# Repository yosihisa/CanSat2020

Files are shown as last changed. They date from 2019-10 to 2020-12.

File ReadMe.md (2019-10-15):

# CanSat2020 
2020ねん9がつ の あーりす はつさんか はつゆうしょう を めざす リポジトリ だよ 。  

## コンセプト
  - 今までにない軽さ 
  - 高い耐久性
  - 高い信頼性
  - 早い開発サイクル
  - 軽くて最強の大型CanSat

## 開発目標  

期間 | モデル | 目標
--- | --- | ---
～2019年12月 | Prototype | 大型機の技術獲得　新要素の動作試験  
～2020年3月 | TRC16 (EM) | 耐久試験①　種コン2連覇  
～2020年8月 | NSE16 (PFM) | 耐久試験②　長距離通信技術の獲得　航続距離の向上  
～2020年9月 | ARLISS2020 (FM) | 最強CanSat完成  

モデル名とタグ名が対応

## 構成

場所 | 名称 | 役割
--- | --- | ---
(あとでA360のURLを貼る) | 構造 | 構造系全般
/PCB | 基板 | 電装系(ハード)
/firmware/main | ソースコード(メイン) | メインMCU
/firmware/sub | ソースコード(サブ) | 画像処理系　画像記録系
/tools | ツール | 運用に便利な道具たち
/doc | Document | 開発メモとか資料とか

## システム図

にゃーん

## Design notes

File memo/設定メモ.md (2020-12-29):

# VScodeでSTM32を開発するためのメモ

## やりたい事
CubeMXでmakefileプロジェクトとして生成→VScodeで編集→VScodeでコンパイル→VScodeで書き込み→VScodeでデバッグ  

## 初回のみ必要な作業(使用するツールのインストール)  
インストールといっても今回は環境変数を変更しないため、適当なディレクトリに展開するだけです。
### ツール
- GNU ARM Embedded Toolchain  
- OpenOCD  
- Make for Windows  
- LibIntl for Windows  
- LibIconv for Windows  
こいつらを`C:\tools`以下に展開  

場所  
- `C:\tools\gcc-arm-none-eabi-9-2019-q4-major-win32\bin`  
- `C:\tools\OpenOCD\0.10.0-12-20190422-2015\bin`  
- `C:\tools\make-3.81-bin\bin`  
- `C:\tools\make-3.81-bin\bin\libintl3.dll`  
- `C:\tools\make-3.81-bin\bin\libiconv2.dll`  

### 拡張機能
- C/C++  
- Cortex-Debug  

## プロジェクトごとに必要な設定  

### .vscode\tasks.json  

```json
{
    "version": "2.0.0",
    "type": "shell",
    "echoCommand": true,
    "tasks": [
        {
            "label": "Build project",
            "command": "make",
            "args": [
                "all",
                "GCC_PATH=C:\\tools\\gcc-arm-none-eabi-9-2019-q4-major-win32\\bin"
            ],
            "options": {
                "env": {
                    "PATH": "C:\\tools\\make-3.81-bin\\bin"
                }
            },
            "problemMatcher": [
                "$gcc"
            ],
            "group": {
                "kind": "build",
                "isDefault": true
            }
        },
        {
            "label": "Clean project",
            "command": "Remove-Item",
            "args": [
                "build",
                "-Recurse"
            ],
            "problemMatcher": [
                "$gcc"
            ],
            "group": {
                "kind": "build",
                "isDefault": true
            }
        }
    ]
}
```

### launch.json

```json
{
    "version": "0.2.0",
    "configurations": [
        {
            "name": "Cortex Debug",
            "cwd": "${workspaceRoot}",
            "executable": "./build/${workspaceFolderBasename}.elf",
            "request": "launch",
            "type": "cortex-debug",
            "servertype": "openocd",
            "configFiles": [
                "board/st_nucleo_f4.cfg"
            ],
            "preLaunchTask": "Build project",
            "armToolchainPath": "C:\\tools\\gcc-arm-none-eabi-9-2019-q4-major-win32\\bin\\",
            "serverpath": "C:\\tools\\OpenOCD\\0.10.0-12-20190422-2015\\bin\\openocd.exe"
        }
    ]
}
```

もしくは

```json

            "configFiles": [
                "interface/stlink-v2-1.cfg",
                "target/stm32f4.cfg"
            ],
```

### makefile  

ソースファイルを追加したら以下の場所にパスを追加する。

```makefile
# C sources
C_SOURCES =  \
Src/main.c \
...
```

RAMやROMの使用率を表示するには以下の設定をしておくと便利。
`,-print-memory-usage`を末尾に追加する。
`printf`で`float`を使う場合も同じように`u _printf_float`を末尾に追加する。

```makefile
# libraries
LIBS = -lc -lm -lnosys 
LIBDIR = 
LDFLAGS = $(MCU) -specs=nano.specs <中略> ,-print-memory-usage
```

### .vscode\c_cpp_properties.json  
必須ではないが設定しておくとintellisenseが機能するようになるので便利。 

```json
{
    "configurations": [
        {
            "name": "STM32",
            "includePath": [
                "${workspaceFolder}/**",
                "C:\\tools\\gcc-arm-none-eabi-9-2019-q4-major-win32\\arm-none-eabi\\include**",
                "C:\\tools\\gcc-arm-none-eabi-9-2019-q4-major-win32\\lib\\gcc\\arm-none-eabi\\9.2.1\\include"
            ],
            "defines": [
                "USE_HAL_DRIVER",
                "STM32F446xx",
                "__weak=__attribute__((weak))"
            ],
            "compilerPath": "C:\\tools\\gcc-arm-none-eabi-9-2019-q4-major-win32\\bin\\arm-none-eabi-gcc",
            "cStandard": "c11",
            "cppStandard": "c++17",
            "intelliSenseMode": "clang-x64"
        }
    ],
    "version": 4
}
```

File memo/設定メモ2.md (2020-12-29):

# ライブラリを共通化するための方法

## やりたい事
CubeMXで生成したファイルと自前のライブラリを共通化しつつ、main.cなどのファイルはプログラムごとに分離したい

## ディレクトリ構成

```
hoge/
　├ .vscode/
　│　├ c_cpp_properties.json
　│　├ launch.json
　│　├ tasks.json
　│　└...
　│
　├ common/      ←自作ライブラリのディレクトリ
　│　├ Inc/
　│　│  └ *.h
　│　└ Src/
　│　   └ *.c
　│
　├ Drivers/     ←CubeMXにより自動生成
　├ Inc/         ←CubeMXにより自動生成
　│
　├ Project1/    ←自分で書くコード1
　│　├ main.c
　│　├ Makefile
　│　├ hogehoge.c
　│　├ hogehoge.h
　│　└...
　│
　├ Project2/    ←自分で書くコード2
　│　├ main.c
　│　├ Makefile
　│　├ hogehoge.c
　│　├ hogehoge.h
　│　└...
　│
　├ Src/        ←CubeMXにより自動生成
　├ .mxproject  ←CubeMXにより自動生成
　├ hoge.ioc    ←CubeMXにより自動生成
　├ Makefile    ←CubeMXにより自動生成
　└ ...
```

## 各種設定  

### CubeMXの設定  
Project Manager -> Code Generator -> Generate peripheral initialaization as a pair of '.c/.h' files per peripheral を有効にする。

### tasks.json  

```json
{
    "version": "2.0.0",
    "type": "shell",
    "echoCommand": true,
    "tasks": [
        {
            "label": "Build project",
            "command": "make",
            "args": [
                "all",
                "GCC_PATH=C:\\tools\\gcc-arm-none-eabi-9-2019-q4-major-win32\\bin",
                "SRC_PATH=${fileDirname}",
                "-j4"
            ],
            "options": {
                "env": {
                    "PATH": "C:\\tools\\make-3.81-bin\\bin"
                }
            },
            "problemMatcher": [
                "$gcc"
            ],
            "group": {
                "kind": "build",
                "isDefault": true
            }
        },
        {
            "label": "Clean project",
            "command": "Remove-Item",
            "args": [
                "${fileDirname}\\build",
                "-Recurse"
            ],
            "problemMatcher": [
                "$gcc"
            ],
            "group": "build"
        }
    ]
}
```

### launch.json

```json
{
    "version": "0.2.0",
    "configurations": [
        {
            "name": "Cortex Debug",
            "cwd": "${workspaceRoot}",
            "executable": "${fileDirname}/build/${workspaceFolderBasename}.elf",
            "request": "launch",
            "type": "cortex-debug",
            "servertype": "openocd",
            "configFiles": [
                "board/st_nucleo_f4.cfg"
            ],
            "preLaunchTask": "Build project",
            "armToolchainPath": "C:\\tools\\gcc-arm-none-eabi-9-2019-q4-major-win32\\bin\\",
            "serverpath": "C:\\tools\\OpenOCD\\0.10.0-12-20190422-2015\\bin\\openocd.exe"
        }
    ]
}
```

### /Makefile
ルートディレクトリのMakefile

```makefile
#先頭に追加
include $(SRC_PATH)\Makefile

# Build path
BUILD_DIR = $(SRC_PATH)\build

# C sources
C_SOURCES =  \
$(C_SRC) \
$(wildcard common/Src/*.c) \
#C_SOURCES
...
```

変更点
- `include $(SRC_PATH)\Makefile` の追加
- `BUILD_DIR` の変更
- `C_SOURCES` の変更
- `C_SOURCES` からCubeMXによって記述された`C_SOURCES`の削除

### Project1/Makefile  
自分で生成した各プロジェクト内のMakefile

```makefile
C_SRC = \
Project1/main.c \
Project1/hogehoge.c \

BUILD_DIR = $(SRC_PATH)\build
```

RAMやROMの使用率を表示するには以下の設定をしておくと便利。
`,-print-memory-usage`を末尾に追加する。  
`printf`で`float`を使う場合も同じように`u _printf_float`を末尾に追加する。

```makefile
# libraries
LIBS = -lc -lm -lnosys 
LIBDIR = 
LDFLAGS = $(MCU) -specs=nano.specs <中略> ,-print-memory-usage
```

### Project1/main.c

自分で作る各プロジェクト内の`main.c`。
CubeMXで自動生成された `Src.main.c`の内容をコピーする。
CubeMXの設定を変更してもこのファイルは更新されないので、設定の変更の度に手動で編集する必要がある。

### .vscode\c_cpp_properties.json  
必須ではないが設定しておくと便利  

```json
{
    "configurations": [
        {
            "name": "STM32",
            "includePath": [
                "${workspaceFolder}/**",
                "C:\\tools\\gcc-arm-none-eabi-9-2019-q4-major-win32\\arm-none-eabi\\include**",
                "C:\\tools\\gcc-arm-none-eabi-9-2019-q4-major-win32\\lib\\gcc\\arm-none-eabi\\9.2.1\\include"
            ],
            "defines": [
                "USE_HAL_DRIVER",
                "STM32F446xx",
                "__weak=__attribute__((weak))"
            ],
            "compilerPath": "C:\\tools\\gcc-arm-none-eabi-9-2019-q4-major-win32\\bin\\arm-none-eabi-gcc",
            "cStandard": "c11",
            "cppStandard": "c++17",
            "intelliSenseMode": "clang-x64"
        }
    ],
    "version": 4
}
```  

## 使い方
各プロジェクトのファイルを編集している状態で`Ctrl+Shift+B`を押すとそのプロジェクトのコンパイルが実行される。  
`.elf`などのファイルは各プロジェクトのディレクトリ内に生成される`build`以下に生成される。  

`F5`を押すとデバッグができる。

## 問題点
- どのプロジェクトをコンパイルするかは、編集中のファイルが存在するディレクトリによって決定しているため、共通ファイルを編集中にコンパイルを実行するとエラーになる。  
- 同じ理由で、各プロジェクト以下にディレクトリを追加してファイルを入れた場合、そのファイルを編集中にコンパイルを実行するとエラーになる。  
- main.cが自動更新されないため、いちいち手動で更新するのが面倒
- ルートディレクトリ以下が汚く見栄えが悪い。
- 最初に設定する項目がやや多い。

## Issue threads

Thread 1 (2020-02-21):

改善案(種コン2020現在)

yosihisa, 2020-02-21:
種コン2020直前時点における改善案をまとめる。
次のバージョンを作るときに修正すべき点のメモ書きである。

### モータの強化
駆動力が圧倒的に足りていない。現状ではトルクを稼ぐために速度が犠牲になっている。
必要トルクは片側で最低2.5kgf·cm (現在のタイヤ直径において)
100rpmだとかなり遅い 高速走行を目指すなら500rpmくらいあってもいいかもしれない。
ラジアル荷重に対する強度も強化する必要あり。

### ボディの再設計
MJF PA12GBを用いたボディの強度は十分であると思われる。
ただし、モータの変更があるため再設計が必要になる。

### タイヤ形状の見直し
製造費が高い。面圧をあそこまで下げる必要は無い。
メジャーを活用した柔軟な展開機構を作れたりしないか？
輪ゴムを用いた衝撃吸収機構は有用。外側にメジャーを用いた展開機構を作れたりしないだろうか。

### 近接センサの見直し
搭載しているToFセンサ(VL53L0X)が事実上使えていないので、省略しても問題ないと思われる。
または、小型の別のセンサに変えるべき。

### 尻尾の強化
発生トルクに対してテールスキッドに用いているメジャーの強度が足らず曲がってしまう。
何らかの方法で強度を上げる必要がある。

### GNSS処理系の見直し
データ欠損がある。ソフト修正で解決するはずであるが、GNSSモジュールの変更を考えてもいいかも。

### 無線機の変更
本格的な長距離通信を狙うのであれば、LoRa系の無線機を使う。

### 充電コネクタの向き
基板設計時唯一のミスともいえるが、+-が逆になっている。

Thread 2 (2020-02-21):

種コン2020開催中止に伴う開発一時凍結

yosihisa, 2020-02-21:
種コン2020開催中止に伴い、プロジェクトを一時凍結する。
再開時期は未定。

現時点での進捗を以下にまとめる

### 未実装
- パラシュート回避動作
- 2段減速用の錘
- パラシュートの紐

### 未検証
- 完成機体での落下試験
- 広い場所での0mゴールまでの走行試験
- End to End試験

### 改善策
別のissuesを参照

### 予備機について
大会中のトラブルに備え予備機を製造予定であったが、プロジェクト再開時には再設計から始まると思うので、現設計での予備機の製造は不要である。
予備機の部品は発注済みであるため、次に示すものが在庫として余っている。

### 予備機部品
- タイヤ 2個 (1セット)
- ボディ 2個 (ナイロン小1個 ナイロン大1個)
- 基板 5枚以上
- 電子部品 (全部品最低1セット以上)
ネジ類は足りていない。

### 凍結前にやること
- ドキュメント・技術解説資料の整理
- 3Dモデルの公開
- ライセンスの明記

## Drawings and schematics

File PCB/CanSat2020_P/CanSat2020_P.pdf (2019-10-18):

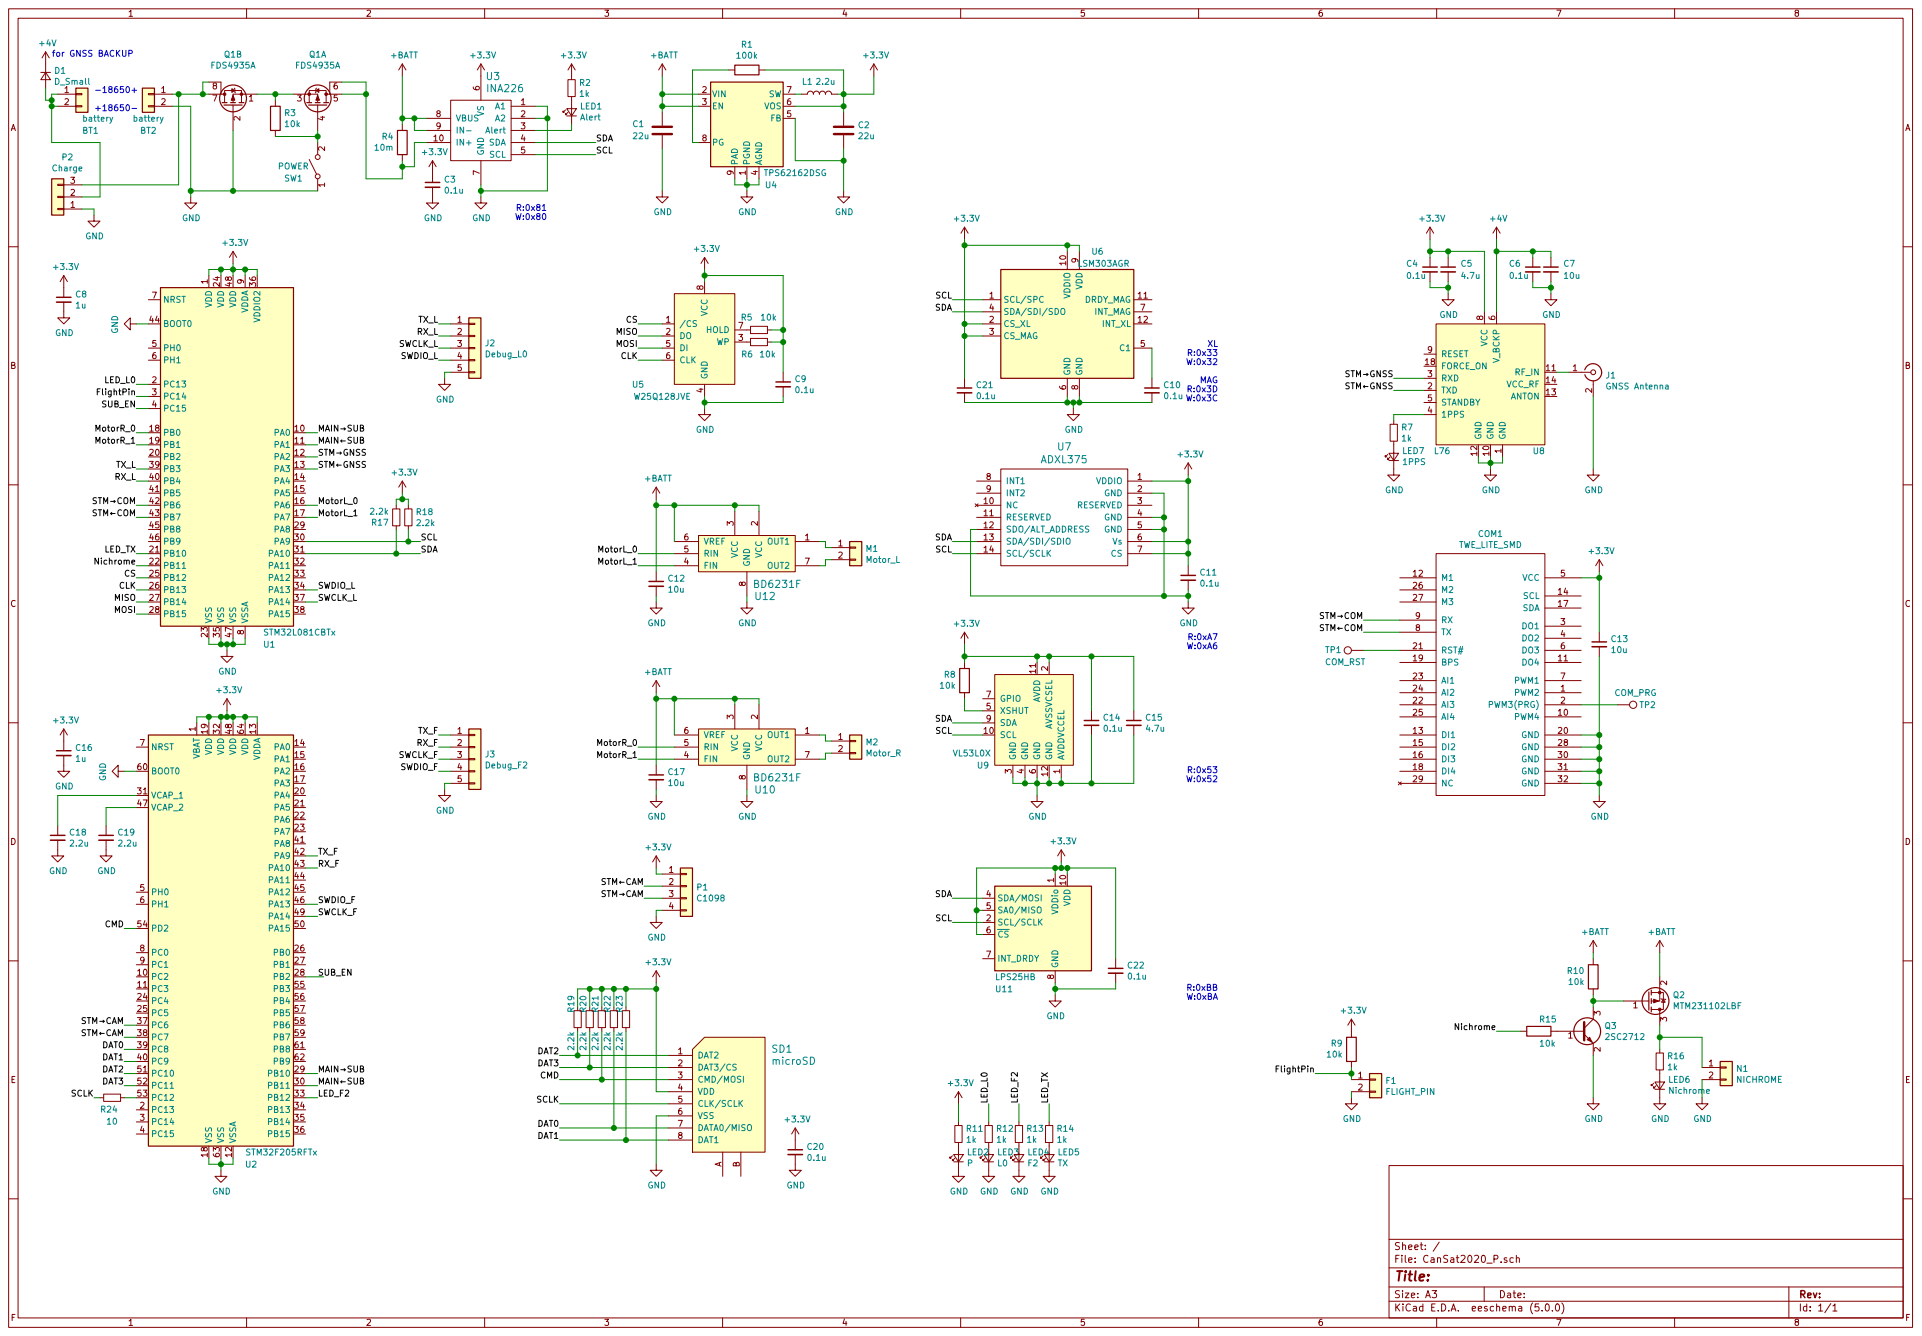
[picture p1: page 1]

4 FB 5 VOS 6 SW 7 PG 8 PAD

9 VDDIO2 36 VSS 23 VSS 35 VSS 47 VSSA

4 DI 5 CLK 6 HOLD 7 VCC

1 GND 10 RF_IN 11 GND 12 ANTON 13 VCC_RF 14 FORCE_ON 18 TXD 2 RXD 3

3 FIN 4 RIN 5 VREF 6 OUT2 GND 7

1 SCL 10 AVDD 11 GND 12 AVSSVCSEL

1 VCAP_1 31 VCAP_2 47 VDD 19 VDD 32 VDD 48 VDD 64 VDDA 13 VSS 18 VSS 63 VSSA 12 U2STM32F205RFTx

1 VDD 10 SCL/SCLK 2 SDA/MOSI 4 SA0/MISO 5 CS 6

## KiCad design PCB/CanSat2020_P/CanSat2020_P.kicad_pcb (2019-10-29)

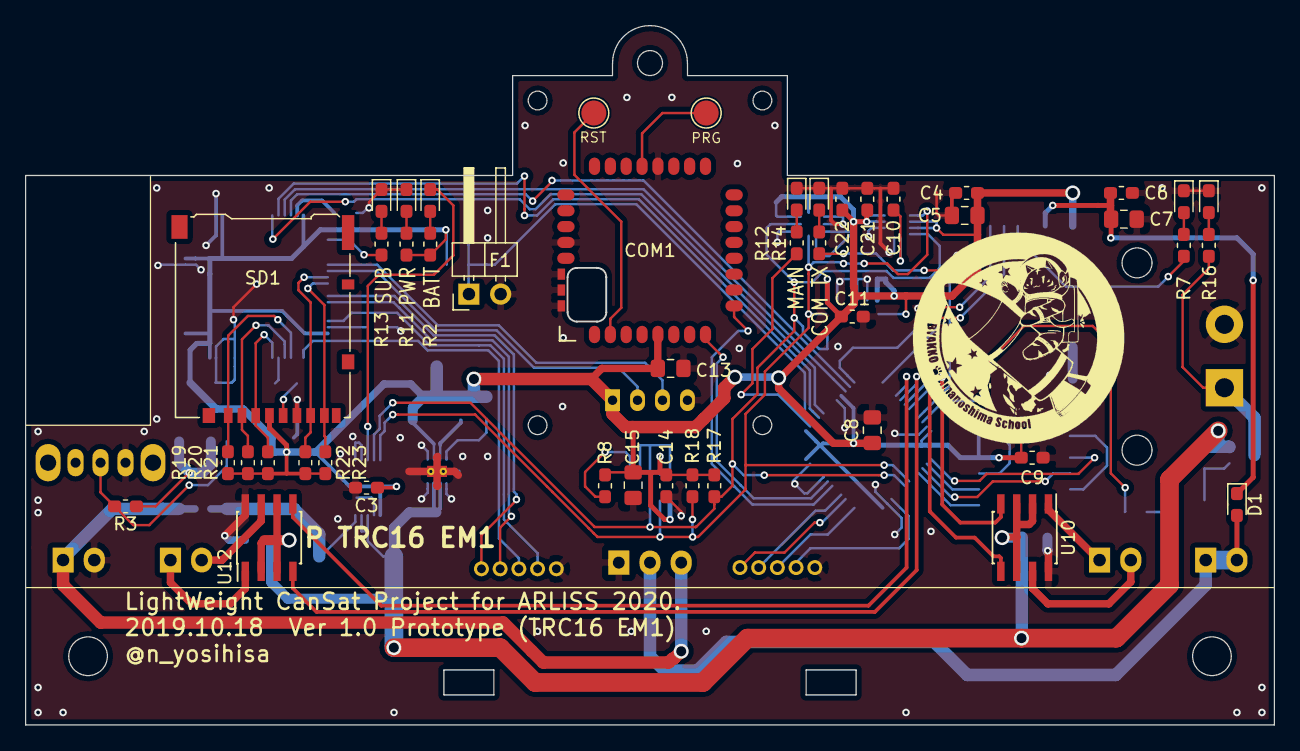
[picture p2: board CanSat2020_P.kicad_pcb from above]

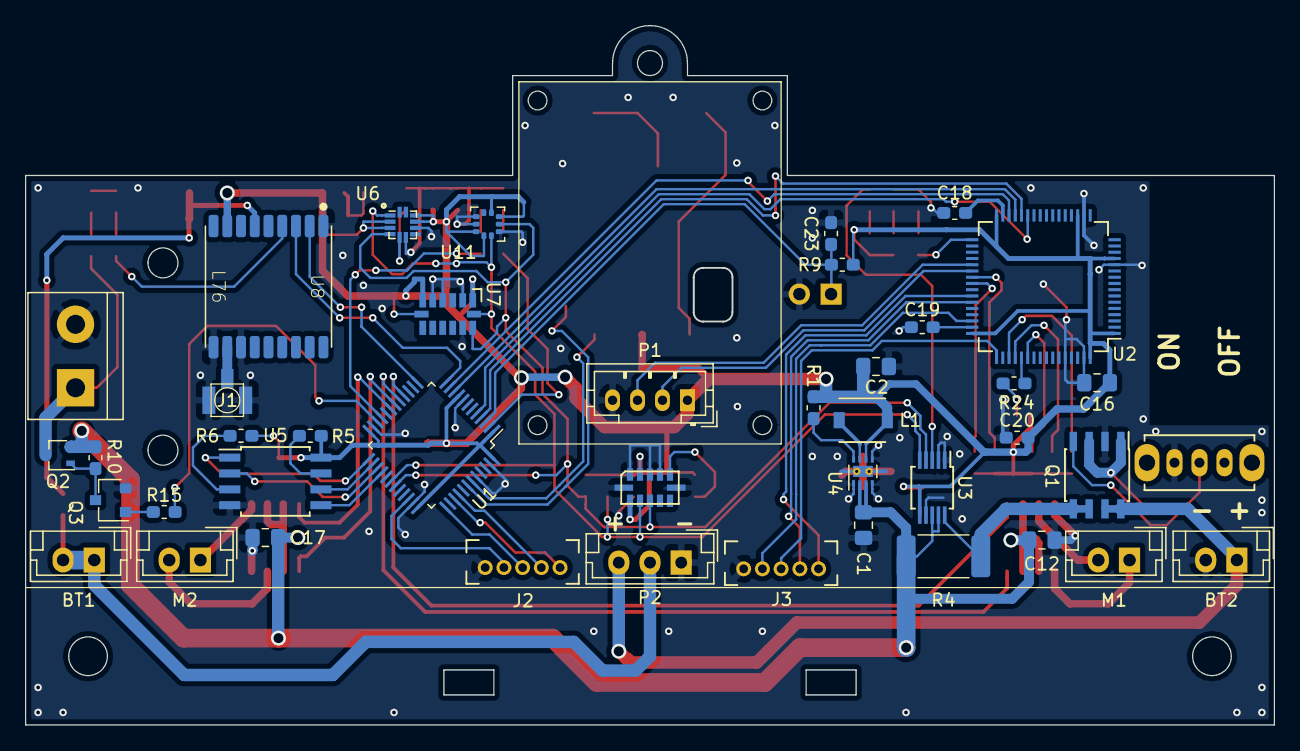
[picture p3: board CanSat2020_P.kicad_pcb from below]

Board: 2 copper layers, 100.0 x 56.0 mm, 87 parts (42 on the bottom side), 76 nets.

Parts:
BT1, BT2: battery; JST_EH_B02B-EH-A_1x02_P2.50mm_Vertical
C1, C2: 22u; C_0805_2012Metric_Pad1.15x1.40mm_HandSolder
C3, C4, C6, C9, C10, C11, C14, C20, C21, C22, C23: 0.1u; C_0603_1608Metric_Pad1.05x0.95mm_HandSolder
C5, C15: 4.7u; C_0805_2012Metric_Pad1.15x1.40mm_HandSolder
C7, C12, C13, C17: 10u; C_0805_2012Metric_Pad1.15x1.40mm_HandSolder
C8, C16: 1u; C_0805_2012Metric_Pad1.15x1.40mm_HandSolder
C18, C19: 2.2u; C_0603_1608Metric_Pad1.05x0.95mm_HandSolder
COM1: TWE_LITE_SMD; TWE-001L-SMD
D1: D_Small; D_0603_1608Metric_Pad1.05x0.95mm_HandSolder
F1: FLIGHT_PIN; PinHeader_1x02_P2.54mm_Horizontal
J1: GNSS Antenna; U.FL-R-SMT-1
J2: Debug_L0; STlink
J3: Debug_F2; STlink
L1: 2.2u; inductor_VLF4012-2R2
LED1: Alert; LED_0603_1608Metric_Pad1.05x0.95mm_HandSolder
LED2: P; LED_0603_1608Metric_Pad1.05x0.95mm_HandSolder
LED3: L0; LED_0603_1608Metric_Pad1.05x0.95mm_HandSolder
LED4: F2; LED_0603_1608Metric_Pad1.05x0.95mm_HandSolder
LED5: TX; LED_0603_1608Metric_Pad1.05x0.95mm_HandSolder
LED6: Nichrome; LED_0603_1608Metric_Pad1.05x0.95mm_HandSolder
LED7: 1PPS; LED_0603_1608Metric_Pad1.05x0.95mm_HandSolder
M1: Motor_L; JST_EH_B02B-EH-A_1x02_P2.50mm_Vertical
M2: Motor_R; JST_EH_B02B-EH-A_1x02_P2.50mm_Vertical
N1: NICHROME; TerminalBlock_bornier-2_P5.08mm
P1: C1098; JST_PH_B4B-PH-K_1x04_P2.00mm_Vertical
P2: Charge; JST_EH_B03B-EH-A_1x03_P2.50mm_Vertical
Q1: FDS4935A; SOIC-8_3.9x4.9mm_P1.27mm
Q2: MTM231102LBF; SOT-323_SC-70
Q3: 2SC2712; SC-59
R1: 100k; R_0603_1608Metric_Pad1.05x0.95mm_HandSolder
R2, R7, R11, R12, R13, R14, R16: 1k; R_0603_1608Metric_Pad1.05x0.95mm_HandSolder
R3, R5, R6, R8, R9, R10, R15: 10k; R_0603_1608Metric_Pad1.05x0.95mm_HandSolder
R4: 10m; R_2512_6332Metric_Pad1.52x3.35mm_HandSolder
R17, R18, R19, R20, R21, R22, R23: 2.2k; R_0603_1608Metric_Pad1.05x0.95mm_HandSolder
R24: 10; R_0603_1608Metric_Pad1.05x0.95mm_HandSolder
SD1: microSD; microSD_HC_Hirose_DM3AT-SF-PEJM5
SW1: POWER; SS-12D01-VG4
TP1: COM_RST; TestPoint_Pad_D2.0mm
TP2: COM_PRG; TestPoint_Pad_D2.0mm
U1: STM32L081CBTx; LQFP-48_7x7mm_P0.5mm
U2: STM32F205RFTx; LQFP-64_10x10mm_P0.5mm
U3: INA226; MSOP-10_3x3mm_P0.5mm
U4: TPS62162DSG; WSON-8-1EP_2x2mm_P0.5mm_EP0.9x1.6mm_ThermalVias
U5: W25Q128JVE; SOIJ-8_5.3x5.3mm_P1.27mm
U6: LSM303AGR; LGA-12_2x2mm_P0.5mm_HandSolder
U7: ADXL375; LGA_CC-14-1
U8: L76
U9: VL53L0X
U10, U12: BD6231F; SOIC-8_3.9x4.9mm_P1.27mm
U11: LPS25HB; ST_HLGA-10_2.5x2.5mm_P0.6mm_LayoutBorder3x2y

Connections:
+3V3: C2.1, C3.1, C4.1, C5.1, C8.1, C9.1, C11.1, C13.1, C14.1, C15.1, C16.1, C20.1, C21.1, C22.1, COM1.5, L1.2, P1.1, R1.2, R2.1, R5.2, R6.1, R8.2, R9.2, R11.1, R17.2, R18.1, R19.2, R20.2, R21.2, R22.2, R23.2, SD1.4, U1.1, U1.9, U1.24, U1.36, U1.48, U2.1, U2.13, U2.19, U2.32, U2.48, U2.64, U3.6, U4.6, U5.8, U6.2, U6.3, U6.9, U6.10, U7.1, U7.6, U7.7, U8.8, U9.2, U9.11, U11.1, U11.5, U11.6, U11.10
+4V: C6.1, C7.1, D1.1, U8.6
+BATT: C1.2, C12.1, C17.1, Q2.2, R4.2, R10.2, U3.8, U3.9, U4.2, U4.3, U10.2, U10.3, U10.6, U12.2, U12.3, U12.6
/CLK: U1.26, U5.6
/CMD: R21.1, SD1.3, U2.54
/CS: U1.25, U5.1
/DAT0: R22.1, SD1.7, U2.39
/DAT1: R23.1, SD1.8, U2.40
/DAT2: R19.1, SD1.1, U2.51
/DAT3: R20.1, SD1.2, U2.52
/FlightPin: C23.1, F1.1, R9.1, U1.3
/IMG_MODE: U1.5, U2.27
/LED_F2: R13.1, U2.33
/LED_L0: R12.1, U1.2
/LED_TX: R14.1, U1.21
/MAIN←SUB: U1.11, U2.30
/MAIN→SUB: U1.10, U2.29
/MISO: U1.27, U5.2
/MOSI: U1.28, U5.5
/MotorL_0: U1.16, U12.5
/MotorL_1: U1.17, U12.4
/MotorR_0: U1.18, U10.5
/MotorR_1: U1.19, U10.4
/Nichrome: R15.1, U1.22
/RX_F: J3.2, U2.43
/RX_L: J2.2, U1.40
/SCL: R18.2, U1.30, U3.5, U6.1, U7.14, U9.10, U11.2
/SCLK: R24.1, SD1.5
/SDA: R17.1, U1.31, U3.4, U6.4, U7.13, U9.9, U11.4
/STM←CAM: P1.2, U2.38
/STM←COM: COM1.8, U1.43
/STM←GNSS: U1.13, U8.2
/STM→CAM: P1.3, U2.37
/STM→COM: COM1.9, U1.42
/STM→GNSS: U1.12, U8.3
/SUB_EN: U1.4, U2.28
/SWCLK_F: J3.3, U2.49
/SWCLK_L: J2.3, U1.37
/SWDIO_F: J3.4, U2.46
/SWDIO_L: J2.4, U1.34
/TX_F: J3.1, U2.42
/TX_L: J2.1, U1.39
GND: BT2.2, C1.1, C2.2, C3.2, C4.2, C5.2, C6.2, C7.2, C8.2, C9.2, C10.2, C11.2, C12.2, C13.2, C14.2, C15.2, C16.2, C17.2, C18.2, C19.2, C20.2, C21.2, C22.2, C23.2, COM1.20, COM1.28, COM1.30, COM1.31, COM1.32, F1.2, J1.2, J2.5, J3.5, LED2.1, LED3.1, LED4.1, LED5.1, LED6.1, LED7.1, N1.2, P1.4, P2.1, Q1.2, Q3.2, SD1.6, SW1.1, U1.8, U1.23, U1.35, U1.44, U1.47, U2.12, U2.18, U2.60, U2.63, U3.1, U3.2, U3.7, U4.1, U4.4, U4.5, U4.9, U5.4, U6.6, U6.8, U7.2, U7.4, U7.5, U7.12, U8.1, U8.10, U8.12, U9.1, U9.3, U9.4, U9.6, U9.12, U10.8, U11.3, U11.8, U11.9, U12.8
unnamed: BT1.1, BT1.2, D1.2, P2.2
unnamed: BT2.1, P2.3, Q1.7, Q1.8
unnamed: C10.1, U6.5
unnamed: C18.1, U2.31
unnamed: C19.1, U2.47
unnamed: COM1.2, TP2.1
unnamed: COM1.21, TP1.1
unnamed: J1.1, U8.11
unnamed: L1.1, U4.7
unnamed: LED1.1, U3.3
unnamed: LED1.2, R2.2
unnamed: LED2.2, R11.2
unnamed: LED3.2, R12.2
unnamed: LED4.2, R13.2
unnamed: LED5.2, R14.2
unnamed: LED6.2, R16.2
unnamed: LED7.2, R7.2
unnamed: M1.1, U12.1
unnamed: M1.2, U12.7
unnamed: M2.1, U10.1
unnamed: M2.2, U10.7
unnamed: N1.1, Q2.3, R16.1
unnamed: Q1.1, Q1.3, R3.1
unnamed: Q1.4, R3.2, SW1.2
unnamed: Q1.5, Q1.6, R4.1, U3.10
unnamed: Q2.1, Q3.3, R10.1
unnamed: Q3.1, R15.2
unnamed: R1.1, U4.8
unnamed: R5.1, U5.7
unnamed: R6.2, U5.3
unnamed: R7.1, U8.4
unnamed: R8.1, U9.5
unnamed: R24.2, U2.53

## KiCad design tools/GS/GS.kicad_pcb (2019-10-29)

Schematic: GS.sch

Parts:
C1, C3: 10u; C_0805_2012Metric_Pad1.15x1.40mm_HandSolder
C2, C4, C7: 0.1u; C_0603_1608Metric_Pad1.05x0.95mm_HandSolder
C5, C6: 47p; C_0603_1608Metric_Pad1.05x0.95mm_HandSolder
CN1: USB-B-MICRO; Micro-USB
D1: PWR; LED_0603_1608Metric_Pad1.05x0.95mm_HandSolder
D2: TX; LED_0603_1608Metric_Pad1.05x0.95mm_HandSolder
D3: RX; LED_0603_1608Metric_Pad1.05x0.95mm_HandSolder
J1: SMA; SMA_Amphenol_901-144_Vertical
R1, R3, R4: 1K; R_0603_1608Metric_Pad1.05x0.95mm_HandSolder
R2: 10k; R_0603_1608Metric_Pad1.05x0.95mm_HandSolder
SW1: RST; SKRPACE010_kai
SW2: PRG; SKRPACE010_kai
TP1: ANT; TestPoint_THTPad_D3.0mm_Drill1.5mm
U1: L78L05_SOT89; SOT-89-3
U2: TWE_LITE_SMD; TWE-001L-SMD-noNTH
U3: FT231XQ; QFN-20-1EP_4x4mm_P0.5mm_EP2.5x2.5mm

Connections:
+3V3: C2.1, C3.1, C4.1, D1.2, D2.2, D3.2, R2.1, U1.1 (OUT), U2.5, U3.20
+5V: C1.2, C7.1, CN1.1, U1.3 (IN), U3.11, U3.12
/ANT: J1.1, TP1.1
/PRG: SW2.2, U2.2, U3.16
/RST: R2.2, SW1.2, U2.21, U3.7
/RXD: U2.8, U3.1
/TXD: U2.9, U3.17
GND: C1.1, C2.2, C3.2, C4.2, C5.1, C6.2, C7.2, CN1.5, CN1.6, CN1.7, J1.2, R1.2, SW1.1, SW2.1, U1.2 (GND), U2.20, U2.28, U2.30, U2.31, U2.32, U3.3, U3.13, U3.21
unnamed: C5.2, CN1.2, U3.9
unnamed: C6.1, CN1.3, U3.8
unnamed: D1.1, R1.1
unnamed: D2.1, R3.1
unnamed: D3.1, R4.1
unnamed: R3.2, U3.15
unnamed: R4.2, U3.14

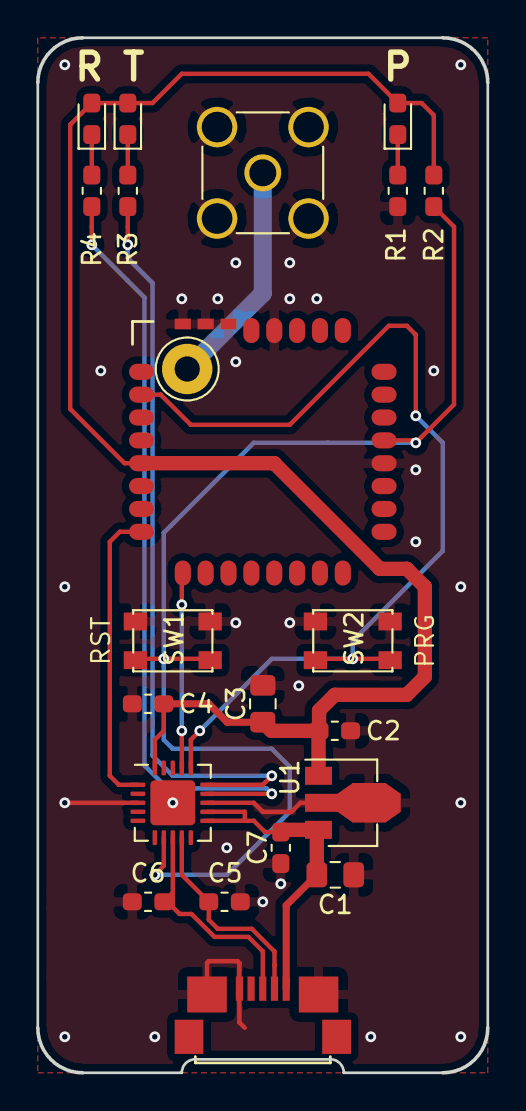
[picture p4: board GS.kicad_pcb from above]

Board: 2 copper layers, 25.0 x 57.5 mm, 22 parts (0 on the bottom side), 15 nets.

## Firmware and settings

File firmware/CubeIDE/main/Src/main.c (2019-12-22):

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

/* Includes ------------------------------------------------------------------*/
#include "main.h"

/* USER CODE BEGIN Includes */
#include <stdio.h>
#include <string.h>

#include "cansat.h"
#include "CUI.h"
#include "gnc.h"

/* USER CODE END Includes */

I2C_HandleTypeDef hi2c1;

SPI_HandleTypeDef hspi2;

TIM_HandleTypeDef htim2;
TIM_HandleTypeDef htim3;

UART_HandleTypeDef huart1;
UART_HandleTypeDef huart2;
UART_HandleTypeDef huart4;
UART_HandleTypeDef huart5;

/* USER CODE BEGIN PV */
void __io_putchar(uint8_t ch) {
	HAL_UART_Transmit(&huart5, &ch, 1, 1);
	HAL_UART_Transmit(&huart1, &ch, 1, 1); //COM
}
/* USER CODE END PV */

void SystemClock_Config(void);
static void MX_GPIO_Init(void);
static void MX_I2C1_Init(void);
static void MX_SPI2_Init(void);
static void MX_TIM3_Init(void);
static void MX_USART1_UART_Init(void);
static void MX_USART2_UART_Init(void);
static void MX_USART4_UART_Init(void);
static void MX_USART5_UART_Init(void);
static void MX_TIM2_Init(void);
/* USER CODE BEGIN 0 */

static img_t img_data = { 0 };
static uint8_t sub_rx_buff[11] = { 0 };
static cansat_t cansat_data;


void HAL_GPIO_EXTI_Callback(uint16_t GPIO_Pin) {
	for (int i = 0; i < 10; i++) {
		HAL_UART_Receive(&huart4, &sub_rx_buff[0], 1, 50);
		if (sub_rx_buff[0] == '$')break;
	}
	HAL_UART_Receive(&huart4, &sub_rx_buff[0], 11, 50);
	if (sub_rx_buff[0] == 'O') {
		img_data.name = (sub_rx_buff[1] << 8) + sub_rx_buff[2];
		img_data.xc = (sub_rx_buff[3] << 8) + sub_rx_buff[4];
		img_data.yc = (sub_rx_buff[5] << 8) + sub_rx_buff[6];
		img_data.s = (sub_rx_buff[7] << 16) + (sub_rx_buff[8] << 8) + sub_rx_buff[9];
	}
	else if (sub_rx_buff[0] == 'o') {
		img_data.name = (sub_rx_buff[2] << 8) + sub_rx_buff[3];
		img_data.xc = (sub_rx_buff[4] << 8) + sub_rx_buff[5];
		img_data.yc = (sub_rx_buff[6] << 8) + sub_rx_buff[7];
		img_data.s = (sub_rx_buff[8] << 16) + (sub_rx_buff[9] << 8) + sub_rx_buff[10];
	}
	else {
		return;
	}
}

void HAL_TIM_PeriodElapsedCallback(TIM_HandleTypeDef* htim) {
	if (htim == &htim2) {
		_motor(&cansat_data.motor, cansat_data.voltage);
	}
}

/* USER CODE END 0 */

/**
  * @brief  The application entry point.
  * @retval int
  */
int main(void)
{
  

  /* MCU Configuration--------------------------------------------------------*/

  /* Reset of all peripherals, Initializes the Flash interface and the Systick. */
  HAL_Init();

  /* Configure the system clock */
  SystemClock_Config();

  /* Initialize all configured peripherals */
  MX_GPIO_Init();
  MX_I2C1_Init();
  MX_SPI2_Init();
  MX_TIM3_Init();
  MX_USART1_UART_Init();
  MX_USART2_UART_Init();
  MX_USART4_UART_Init();
  MX_USART5_UART_Init();
  MX_TIM2_Init();
  /* USER CODE BEGIN 2 */


  //---------------------------------------Initialization BEGIN------------------------------------------------
  HAL_NVIC_DisableIRQ(EXTI4_15_IRQn);

  HAL_GPIO_WritePin(Nichrome_GPIO_Port, Nichrome_Pin, GPIO_PIN_RESET);

  HAL_Delay(500);

  printf("CanSat Main\n");

  HAL_GPIO_WritePin(LED_L0_GPIO_Port, LED_L0_Pin, GPIO_PIN_SET);
  HAL_Delay(200);
  HAL_GPIO_WritePin(LED_L0_GPIO_Port, LED_L0_Pin, GPIO_PIN_RESET);

  printf("INA226  = %02X\n", ina226_who_am_i());
  printf("LPS25HB = %01X\n", lps25h_who_am_i());
  printf("ADXL375 = %01X\n", adxl375_who_am_i());
  printf("JEDECID = %lX\n", flash_read_ID());

  init_I2C();
  init_gnss();
  init_pwm(&cansat_data.motor);

  update_sensor(&cansat_data);
  printf("TIME %02d:%02d:%02d\n", cansat_data.gnss.hh, cansat_data.gnss.mm, cansat_data.gnss.ss);

  cansat_data.mode = 0;
  cansat_data.log_num = 0;

  cansat_data.press_lpf   = cansat_data.press;
  cansat_data.press_d     = 0;
  cansat_data.press_d_lpf = 0;
  cansat_data.press_d_raw = 0;

  motor_Speed(&cansat_data.motor, 0, 0);
  motorStop();

  set_goalFromEEPROM(0);

  cansat_data.flash_address = get_startAddress(cansat_data.gnss.hh, cansat_data.gnss.mm, cansat_data.gnss.ss);
 
  printf("Flash address 0x%lX\n", cansat_data.flash_address);

  HAL_NVIC_EnableIRQ(EXTI4_15_IRQn);
  HAL_TIM_Base_Start_IT(&htim2);
  //---------------------------------------Initialization END------------------------------------------------

  /* USER CODE END 2 */

  /* Infinite loop */
  /* USER CODE BEGIN WHILE */
  while (1)
  {

	  //Enter CUI Mode
	  if (get_char(20) == 'q') {
		  HAL_NVIC_DisableIRQ(EXTI4_15_IRQn);
		  HAL_TIM_Base_Stop_IT(&htim2);
		  motorStop();

		  CUI_main();

		  HAL_NVIC_EnableIRQ(EXTI4_15_IRQn);
		  HAL_TIM_Base_Start_IT(&htim2);
	  };

	  //Update
	  update_sensor(&cansat_data);
	  cansat_data.img = img_data;

	  //Calculation
	  switch (cansat_data.mode) {
	  case 0: //初回のみ
		  cansat_data.mode = 1;
		  break;
	  case 1:
		  mode1_Standby(&cansat_data);
		  break;
	  case 2:
		  mode2_Descent(&cansat_data);
		  break;
	  case 3:
		  mode3_Separation(&cansat_data);
		  break;
	  case 4:
		  mode4_Avoidance(&cansat_data);
		  break;
	  case 5:
		  mode5_Calibration(&cansat_data);
		  break;
	  case 6:
		  mode6_GNSS(&cansat_data);
		  break;
	  case 7:
		  mode7_Optical(&cansat_data);
		  break;
	  case 8:
		  mode8_Goal(&cansat_data);
		  break;
	  default:
		  motor_Speed(&cansat_data.motor, 0, 0);
		  break;
	  }

	  //Save and Print
	  write_log(&cansat_data);


	  HAL_GPIO_TogglePin(LED_L0_GPIO_Port, LED_L0_Pin);

  }
  /* USER CODE END 3 */
}

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


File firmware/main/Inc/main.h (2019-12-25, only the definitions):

#define LED_L0_Pin GPIO_PIN_13
#define LED_L0_GPIO_Port GPIOC
#define FLIGHT_PIN_Pin GPIO_PIN_14
#define FLIGHT_PIN_GPIO_Port GPIOC
#define SUB_IT_Pin GPIO_PIN_15
#define SUB_IT_GPIO_Port GPIOC
#define SUB_IT_EXTI_IRQn EXTI4_15_IRQn
#define SUB_MODE_Pin GPIO_PIN_0
#define SUB_MODE_GPIO_Port GPIOH
#define SUB_TX_Pin GPIO_PIN_0
#define SUB_TX_GPIO_Port GPIOA
#define SUB_RX_Pin GPIO_PIN_1
#define SUB_RX_GPIO_Port GPIOA
#define GNSS_TX_Pin GPIO_PIN_2
#define GNSS_TX_GPIO_Port GPIOA
#define GNSS_RX_Pin GPIO_PIN_3
#define GNSS_RX_GPIO_Port GPIOA
#define LED_TX_Pin GPIO_PIN_10
#define LED_TX_GPIO_Port GPIOB
#define Nichrome_Pin GPIO_PIN_11
#define Nichrome_GPIO_Port GPIOB
#define SPI2_CS_Pin GPIO_PIN_12
#define SPI2_CS_GPIO_Port GPIOB
#define PC_TX_Pin GPIO_PIN_3
#define PC_TX_GPIO_Port GPIOB
#define PC_RX_Pin GPIO_PIN_4
#define PC_RX_GPIO_Port GPIOB
#define COM_TX_Pin GPIO_PIN_6
#define COM_TX_GPIO_Port GPIOB
#define COM_RX_Pin GPIO_PIN_7
#define COM_RX_GPIO_Port GPIOB

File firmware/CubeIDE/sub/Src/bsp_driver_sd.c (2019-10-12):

/**
 ******************************************************************************
  * @file    bsp_driver_sd.c for F2 (based on stm322xg_eval_sd.c)
  * @brief   This file includes a generic uSD card driver.
  ******************************************************************************
  * @attention
  *
  * <h2><center>&copy; Copyright (c) 2019 STMicroelectronics.
  * All rights reserved.</center></h2>
  *
  * This software component is licensed by ST under Ultimate Liberty license
  * SLA0044, the "License"; You may not use this file except in compliance with
  * the License. You may obtain a copy of the License at:
  *                             www.st.com/SLA0044
  *
  ******************************************************************************
  */

#ifdef OLD_API
/* kept to avoid issue when migrating old projects. */
#else
/* USER CODE BEGIN FirstSection */
/* can be used to modify / undefine following code or add new definitions */
/* USER CODE END FirstSection */
/* Includes ------------------------------------------------------------------*/
#include "bsp_driver_sd.h"

/* Extern variables ---------------------------------------------------------*/ 
  
extern SD_HandleTypeDef hsd;

/* USER CODE BEGIN BeforeInitSection */
/* can be used to modify / undefine following code or add code */
/* USER CODE END BeforeInitSection */
/**
  * @brief  Initializes the SD card device.
  * @retval SD status
  */
uint8_t BSP_SD_Init(void)
{
  uint8_t sd_state = MSD_OK;
  /* Check if the SD card is plugged in the slot */
  if (BSP_SD_IsDetected() != SD_PRESENT)
  {
    return MSD_ERROR;
  }
  /* HAL SD initialization */
  sd_state = HAL_SD_Init(&hsd);
  /* Configure SD Bus width (4 bits mode selected) */
  if (sd_state == MSD_OK)
  {
    /* Enable wide operation */
    if (HAL_SD_ConfigWideBusOperation(&hsd, SDIO_BUS_WIDE_4B) != HAL_OK)
    {
      sd_state = MSD_ERROR;
    }
  }

  return sd_state;
}
/* USER CODE BEGIN AfterInitSection */
/* can be used to modify previous code / undefine following code / add code */
/* USER CODE END AfterInitSection */

/**
  * @brief  Configures Interrupt mode for SD detection pin.
  * @retval Returns 0 in success otherwise 1. 
  */
uint8_t BSP_SD_ITConfig(void)
{  
  /* TBI: add user code here depending on the hardware configuration used */
  
  return (uint8_t)0;
}

/** @brief  SD detect IT treatment
  */
void BSP_SD_DetectIT(void)
{
  /* TBI: add user code here depending on the hardware configuration used */
}

/** @brief  SD detect IT detection callback
  */
__weak void BSP_SD_DetectCallback(void)
{
  /* NOTE: This function Should not be modified, when the callback is needed,
     the BSP_SD_DetectCallback could be implemented in the user file
  */ 
}

/* USER CODE BEGIN BeforeReadBlocksSection */
/* can be used to modify previous code / undefine following code / add code */
/* USER CODE END BeforeReadBlocksSection */
/**
  * @brief  Reads block(s) from a specified address in an SD card, in polling mode.
  * @param  pData: Pointer to the buffer that will contain the data to transmit
  * @param  ReadAddr: Address from where data is to be read  
  * @param  NumOfBlocks: Number of SD blocks to read 
  * @param  Timeout: Timeout for read operation
  * @retval SD status
  */
uint8_t BSP_SD_ReadBlocks(uint32_t *pData, uint32_t ReadAddr, uint32_t NumOfBlocks, uint32_t Timeout)
{
  uint8_t sd_state = MSD_OK;
  
  if (HAL_SD_ReadBlocks(&hsd, (uint8_t *)pData, ReadAddr, NumOfBlocks, Timeout) != HAL_OK)
  {
    sd_state = MSD_ERROR;
  }

  return sd_state;  
}

/* USER CODE BEGIN BeforeWriteBlocksSection */
/* can be used to modify previous code / undefine following code / add code */
/* USER CODE END BeforeWriteBlocksSection */
/**
  * @brief  Writes block(s) to a specified address in an SD card, in polling mode. 
  * @param  pData: Pointer to the buffer that will contain the data to transmit
  * @param  WriteAddr: Address from where data is to be written
  * @param  NumOfBlocks: Number of SD blocks to write
  * @param  Timeout: Timeout for write operation
  * @retval SD status
  */
uint8_t BSP_SD_WriteBlocks(uint32_t *pData, uint32_t WriteAddr, uint32_t NumOfBlocks, uint32_t Timeout)
{
  uint8_t sd_state = MSD_OK;
  
  if (HAL_SD_WriteBlocks(&hsd, (uint8_t *)pData, WriteAddr, NumOfBlocks, Timeout) != HAL_OK) 
  {
    sd_state = MSD_ERROR;
  }

  return sd_state;  
}

/* USER CODE BEGIN BeforeReadDMABlocksSection */
/* can be used to modify previous code / undefine following code / add code */
/* USER CODE END BeforeReadDMABlocksSection */
/**
  * @brief  Reads block(s) from a specified address in an SD card, in DMA mode.
  * @param  pData: Pointer to the buffer that will contain the data to transmit
  * @param  ReadAddr: Address from where data is to be read
  * @param  NumOfBlocks: Number of SD blocks to read 
  * @retval SD status
  */
uint8_t BSP_SD_ReadBlocks_DMA(uint32_t *pData, uint32_t ReadAddr, uint32_t NumOfBlocks)
{
  uint8_t sd_state = MSD_OK;
  
  /* Read block(s) in DMA transfer mode */
  if (HAL_SD_ReadBlocks_DMA(&hsd, (uint8_t *)pData, ReadAddr, NumOfBlocks) != HAL_OK)
  {
    sd_state = MSD_ERROR;
  }
  
  return sd_state; 
}

/* USER CODE BEGIN BeforeWriteDMABlocksSection */
/* can be used to modify previous code / undefine following code / add code */
/* USER CODE END BeforeWriteDMABlocksSection */
/**
  * @brief  Writes block(s) to a specified address in an SD card, in DMA mode.
  * @param  pData: Pointer to the buffer that will contain the data to transmit
  * @param  WriteAddr: Address from where data is to be written
  * @param  NumOfBlocks: Number of SD blocks to write 
  * @retval SD status
  */
uint8_t BSP_SD_WriteBlocks_DMA(uint32_t *pData, uint32_t WriteAddr, uint32_t NumOfBlocks)
{
  uint8_t sd_state = MSD_OK;
  
  /* Write block(s) in DMA transfer mode */
  if (HAL_SD_WriteBlocks_DMA(&hsd, (uint8_t *)pData, WriteAddr, NumOfBlocks) != HAL_OK)
  {
    sd_state = MSD_ERROR;
  }
  
  return sd_state; 
}

/* USER CODE BEGIN BeforeEraseSection */
/* can be used to modify previous code / undefine following code / add code */
/* USER CODE END BeforeEraseSection */
/**
  * @brief  Erases the specified memory area of the given SD card. 
  * @param  StartAddr: Start byte address
  * @param  EndAddr: End byte address
  * @retval SD status
  */
uint8_t BSP_SD_Erase(uint32_t StartAddr, uint32_t EndAddr)
{
  uint8_t sd_state = MSD_OK;
  
  if (HAL_SD_Erase(&hsd, StartAddr, EndAddr) != HAL_OK)  
  {
    sd_state = MSD_ERROR;
  }

  return sd_state;
}

/* USER CODE BEGIN BeforeHandlersSection */
/* can be used to modify previous code / undefine following code / add code */
/* USER CODE END BeforeHandlersSection */
/**
  * @brief  Handles SD card interrupt request.
  */
void BSP_SD_IRQHandler(void)
{
  HAL_SD_IRQHandler(&hsd);
}

/**
  * @brief  Handles SD DMA Tx transfer interrupt request.
  */
void BSP_SD_DMA_Tx_IRQHandler(void)
{
  HAL_DMA_IRQHandler(hsd.hdmatx); 
}
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

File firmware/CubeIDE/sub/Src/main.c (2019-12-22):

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

/* Includes ------------------------------------------------------------------*/
#include "main.h"
#include "fatfs.h"

/* USER CODE BEGIN Includes */
#include <stdio.h>
#include <string.h>
#include "sd.h"
#include "C1098.h"
#include "jpeg_SW.h"
/* USER CODE END Includes */

SD_HandleTypeDef hsd;

UART_HandleTypeDef huart1;
UART_HandleTypeDef huart3;
UART_HandleTypeDef huart6;

/* USER CODE BEGIN PV */
void __io_putchar(uint8_t ch) {
	HAL_UART_Transmit(&huart1, &ch, 1, 1);
	//1:PC 3:main 6:cam
}
/* USER CODE END PV */

void SystemClock_Config(void);
static void MX_GPIO_Init(void);
static void MX_SDIO_SD_Init(void);
static void MX_USART1_UART_Init(void);
static void MX_USART3_UART_Init(void);
static void MX_USART6_UART_Init(void);
/* USER CODE BEGIN PFP */

#define MAIN_RX_BUFF_SIZE 128
#define MAIN_RX_BUFF_NUM 40
static int main_rx_buff_index;
static unsigned int count_rxIT;
static uint8_t main_rx_buff[MAIN_RX_BUFF_SIZE * MAIN_RX_BUFF_NUM];

/* USER CODE END PFP */

/* USER CODE BEGIN 0 */

void HAL_UART_RxCpltCallback(UART_HandleTypeDef* UartHandle) {
	if (UartHandle->Instance == USART3) {
		count_rxIT++;
		main_rx_buff_index++;
		main_rx_buff_index = main_rx_buff_index % MAIN_RX_BUFF_NUM;
		__HAL_UART_CLEAR_OREFLAG(&huart3);
		__HAL_UART_CLEAR_NEFLAG(&huart3);
		__HAL_UART_CLEAR_FEFLAG(&huart3);
		__HAL_UART_DISABLE_IT(&huart3, UART_IT_PE);
		__HAL_UART_DISABLE_IT(&huart3, UART_IT_ERR);
        HAL_UART_Receive_IT(&huart3, &main_rx_buff[main_rx_buff_index * MAIN_RX_BUFF_SIZE], MAIN_RX_BUFF_SIZE);
	}
}

void reset_main_uart() {
	HAL_UART_DeInit(&huart3);
	printf("HAL_UART_DeInit(&huart3)\n");
	HAL_UART_Init(&huart3);
	printf("HAL_UART_Init(&huart3)\n");
	__HAL_UART_CLEAR_OREFLAG(&huart3);
	__HAL_UART_CLEAR_NEFLAG(&huart3);
	__HAL_UART_CLEAR_FEFLAG(&huart3);
	__HAL_UART_DISABLE_IT(&huart3, UART_IT_PE);
	__HAL_UART_DISABLE_IT(&huart3, UART_IT_ERR);
	HAL_UART_Receive_IT(&huart3, &main_rx_buff[main_rx_buff_index * MAIN_RX_BUFF_SIZE], MAIN_RX_BUFF_SIZE);
}
/* USER CODE END 0 */

/**
  * @brief  The application entry point.
  * @retval int
  */
int main(void)
{
  

  /* MCU Configuration--------------------------------------------------------*/

  /* Reset of all peripherals, Initializes the Flash interface and the Systick. */
  HAL_Init();

  /* Configure the system clock */
  SystemClock_Config();

  /* Initialize all configured peripherals */
  MX_GPIO_Init();
  MX_SDIO_SD_Init();
  MX_USART1_UART_Init();
  MX_USART3_UART_Init();
  MX_USART6_UART_Init();
  MX_FATFS_Init();
  /* USER CODE BEGIN 2 */
  
  static IODEV jpeg;
  uint32_t jpeg_num = 0;

  int c = 0;
  int error_count = 0;
  uint8_t written_index;

  printf("SUB\n");

  memset(&main_rx_buff[0], 0, MAIN_RX_BUFF_SIZE * MAIN_RX_BUFF_NUM);

  while (1) {
	  CAMERARESULT  res = init_C1098();
	  if (res == CAMERA_OK)break;
	  else printf("init_C1098() error: %u \n", res);
  }

  printf("Init Camera\n");

  sd_init();

  changeMode(GOAL);

  count_rxIT = 0;
  main_rx_buff_index = 0;
  written_index = main_rx_buff_index;

  __HAL_UART_CLEAR_OREFLAG(&huart3);
  __HAL_UART_CLEAR_NEFLAG(&huart3);
  __HAL_UART_CLEAR_FEFLAG(&huart3);
  __HAL_UART_DISABLE_IT(&huart3, UART_IT_PE);
  __HAL_UART_DISABLE_IT(&huart3, UART_IT_ERR);
  HAL_UART_Receive_IT(&huart3, &main_rx_buff[main_rx_buff_index* MAIN_RX_BUFF_SIZE], MAIN_RX_BUFF_SIZE);

  /* USER CODE END 2 */

  /* Infinite loop */
  /* USER CODE BEGIN WHILE */
  while (1)
  {
    /* USER CODE END WHILE */

    /* USER CODE BEGIN 3 */

      //Change Target Color
	  GPIO_PinState mode = HAL_GPIO_ReadPin(MODE_GPIO_Port, MODE_Pin);
	  changeMode(mode);

	  printf("%4d %c  ", c, (mode == GOAL ? 'G' : 'P'));

      //Get Picture
	  for (int n = 0; n < 5; n++) {
		  while (snapShot() != CAMERA_OK);
		  getPicture(jpeg.data, MAX_SIZE, &jpeg.size);
		  if (jpeg.size > 1024)break;
	  }

	  sd_writeJpg(jpeg.data, jpeg.size, &jpeg_num);

      //Decode
	  if (decode(&jpeg) == 0) {
		  HAL_GPIO_WritePin(LED_GPIO_Port, LED_Pin, GPIO_PIN_SET);
	  }
	  printf("%ldB %05ld.jpg  ", jpeg.size, jpeg_num);
	  printf("xc=%3ld yc=%3ld s=%5ld ", jpeg.xc, jpeg.yc, jpeg.s);
	  
	  //Transmit Image Data
	  HAL_GPIO_WritePin(MAIN_IT_GPIO_Port, MAIN_IT_Pin, GPIO_PIN_SET);
	  HAL_Delay(1);
	  uint8_t tx_buff[11];
	  tx_buff[0] = '$';
	  HAL_UART_Transmit(&huart3, tx_buff, 1, 15);
	  tx_buff[0] = 'O';
	  tx_buff[1] = (uint8_t)(jpeg_num >> 8);
	  tx_buff[2] = (uint8_t)(jpeg_num);
	  tx_buff[3] = (uint8_t)(jpeg.xc >> 8);
	  tx_buff[4] = (uint8_t)(jpeg.xc);
	  tx_buff[5] = (uint8_t)(jpeg.yc >> 8);
	  tx_buff[6] = (uint8_t)(jpeg.yc);
	  tx_buff[7] = (uint8_t)(jpeg.s >> 16);
	  tx_buff[8] = (uint8_t)(jpeg.s >> 8);
	  tx_buff[9] = (uint8_t)(jpeg.s);
	  tx_buff[10] = 'o';
	  HAL_UART_Transmit(&huart3, tx_buff, 11, 15);
	  HAL_GPIO_WritePin(MAIN_IT_GPIO_Port, MAIN_IT_Pin, GPIO_PIN_RESET);

	  //LOG DATA
	  printf("c = %d", count_rxIT);
	  int fw_res = 0;
	  while (1) {
		  if (written_index == main_rx_buff_index) {
			  if (fw_res == 0)HAL_GPIO_WritePin(LED_GPIO_Port, LED_Pin, GPIO_PIN_RESET);
			  break;
		  }
		  fw_res = sd_writeLog((char*)& main_rx_buff[written_index * MAIN_RX_BUFF_SIZE], MAIN_RX_BUFF_SIZE);
		  written_index++;
		  written_index = written_index % MAIN_RX_BUFF_NUM;
	  }
	  if (count_rxIT == 0) {
		  error_count++;
		  if (error_count == 2) {
			  reset_main_uart();
		  }
	  }
	  else {
		  error_count = 0;
	  }
	  count_rxIT = 0;


	  printf("\n");
	  c++;
  }
  /* USER CODE END 3 */
}

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


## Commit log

2019-10-12 Add main,sub 初期コード
2019-10-16 Add schematic
    [CanSat2020_P.kicad_pcb, CanSat2020_P.sch]
2019-10-16 Update Pin assignment
2019-10-16 Add LPS25HBTR
    [CanSat2020_P.sch]
2019-10-17 Update PCB
    [CanSat2020_P.kicad_pcb, CanSat2020_P.sch]
2019-10-18 Add GS
    [CanSat2020_P.sch, GS.kicad_pcb, GS.sch]
2019-10-29 Update GS
    [GS.kicad_pcb]
2019-10-29 Update PCB
    TRC16 EM1 発注
    [CanSat2020_P.kicad_pcb, CanSat2020_P.sch]
2019-10-29 Add main_sensor_test
    INA226動作確認
2019-10-31 VL53L0Xが使えなかった
2019-10-31 Update sensor_test
2019-10-31 Add main_UART
    NMEA確認 TWELITE書き込み用
2019-11-02 Updata SUB (浮動小数点演算の廃止)
2019-11-03 Fixed UART RX Interrupt
    [main.c, main_sensor_test.ioc, sub.ioc]
2019-11-13 Add PWM
2019-12-12 Update Source.cpp
    2色に対応
2019-12-13 Update Save LOG ,print LOG
2019-12-17 Update CUI
    CUIの機能が一通り完成した！
2019-12-21 走行試験(1221)
2019-12-22 log 修正
2019-12-22 速度推定 パラメータ更新
2019-12-25 開発環境の変更
    [st_f2.cfg]
2019-12-26 Update Optical Navigation
    [st_f2.cfg]
2020-02-12 モータ大型化に対応
2020-02-14 画像認識 パラメータ調整
2020-12-29 環境構築メモ追加

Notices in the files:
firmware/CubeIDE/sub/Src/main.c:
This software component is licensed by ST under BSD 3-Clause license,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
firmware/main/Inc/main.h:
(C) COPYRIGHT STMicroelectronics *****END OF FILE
